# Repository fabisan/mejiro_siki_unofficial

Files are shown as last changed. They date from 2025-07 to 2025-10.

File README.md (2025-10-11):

# 初めに
勝手に作成したメジロ式配列のキーボードです
完成度は低いです

## 各フォルダの中身
CircuitBoard 
  回路図とガーバーデータ、KiCADデータ 
  JLCPCB
  PCB仕様は
    異なるデザイン：2
    納品形式：面付け済み
  HASL無鉛:$18.80 (5枚)

Firmware
  ファームウェアファイル

KeyCaps
  1uと2uのキーのSTLファイル、1個のみ・複数個バージョン
  JLC3DP
  複数個バージョン
    1u: $0.63
    2U: $1.47

plates
  アクリルプレートの加工図面
  遊舎工房に依頼したらすんなりデザインチェックOKでした
  作り直すので消しました

## 直したいところ
- 2Uキーの幅はもう少し長いと見た目がきれい
- ステムの穴はわずかに大きい。
    応急処置方法:穴をふさぐようにマステを貼って、スイッチに押し付けて取り付ける。(ChatGPT先生直伝)
- スタビライザーを付けたい。Y,#,*がわずかにぐらつく -> ステムを見直したら個人的に要らない気がした
- nキーは、t,kの逆側中央を少し盛り上げたい。完全に平面だと押しづらい
- Pro Micro版も作りたい -> 結局RP2040になりました

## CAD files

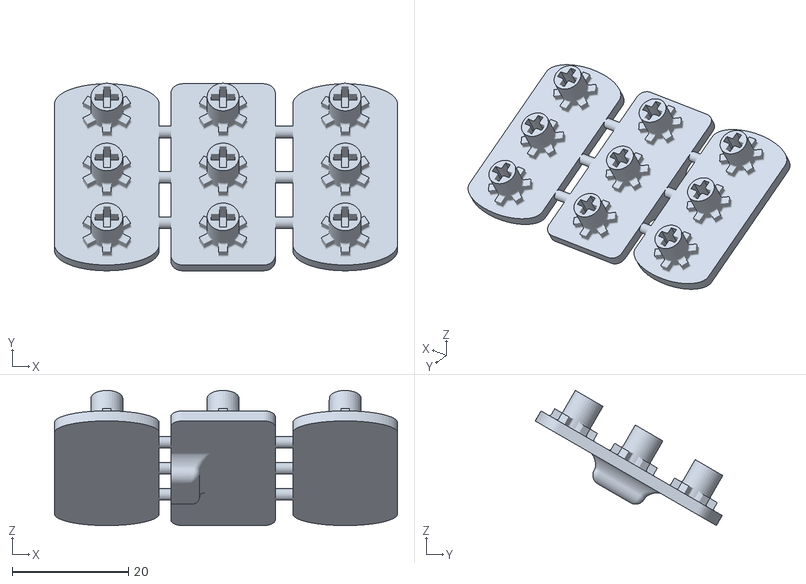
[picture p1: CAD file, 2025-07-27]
KeyCaps/mejiro_2ukeys v2.stl
59.0 x 32.3 x 23.3

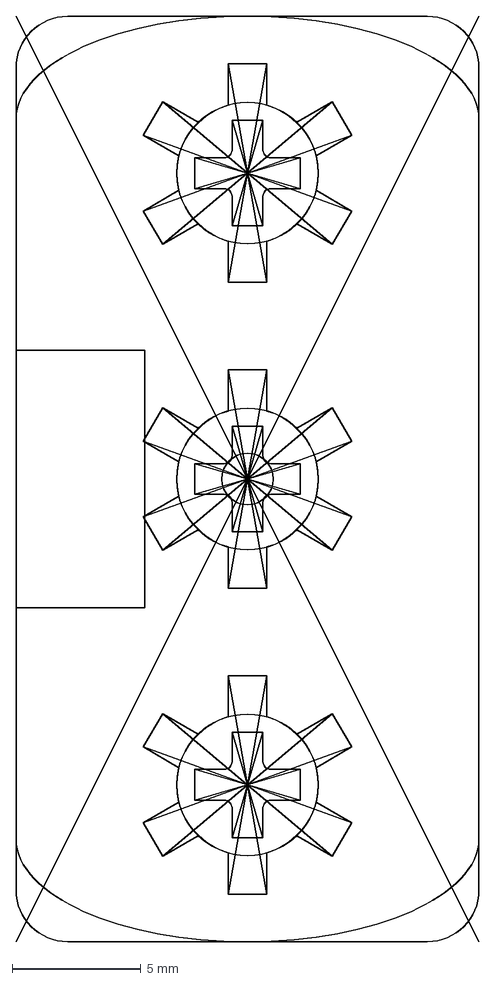
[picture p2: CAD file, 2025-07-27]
KeyCaps/mejiro_2uThumbs v3.dxf
18.0 x 36.0 mm

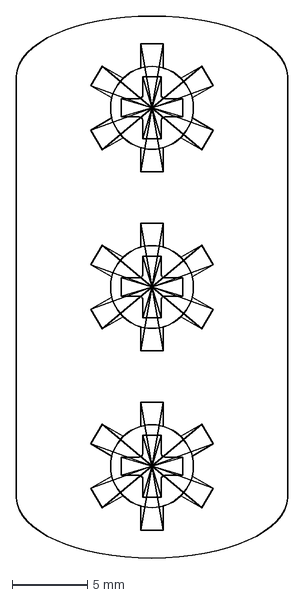
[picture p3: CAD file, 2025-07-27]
KeyCaps/mejiro_2uキー v5.dxf
18.0 x 36.0 mm

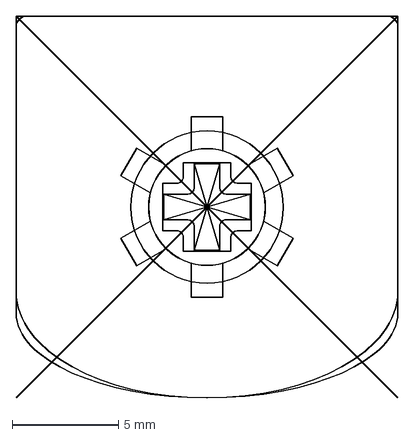
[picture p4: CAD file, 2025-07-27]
KeyCaps/mejiro_1u v8.dxf
18.0 x 18.0 mm

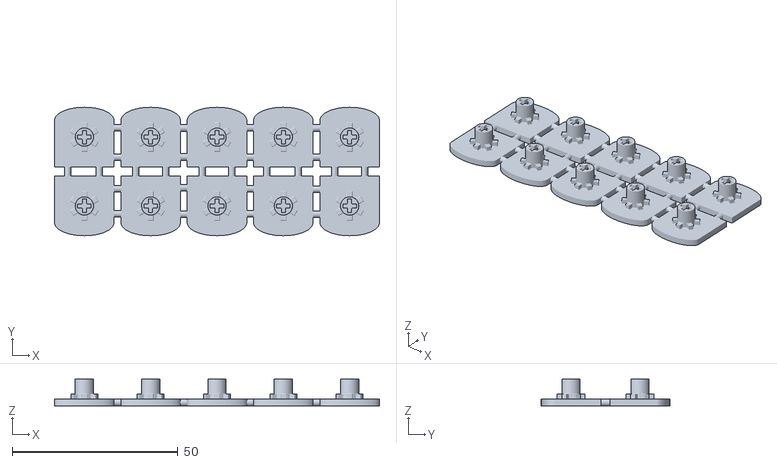
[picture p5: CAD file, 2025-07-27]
KeyCaps/mejiro_1u_x10 v3.stl
98.0 x 38.8 x 8.00

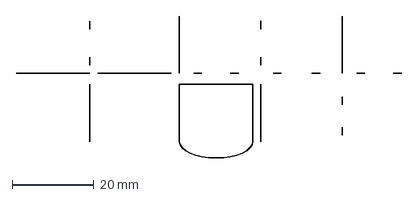
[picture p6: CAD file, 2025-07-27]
KeyCaps/mejiro_1u_x10 v4.dxf
94.5 x 34.8 mm

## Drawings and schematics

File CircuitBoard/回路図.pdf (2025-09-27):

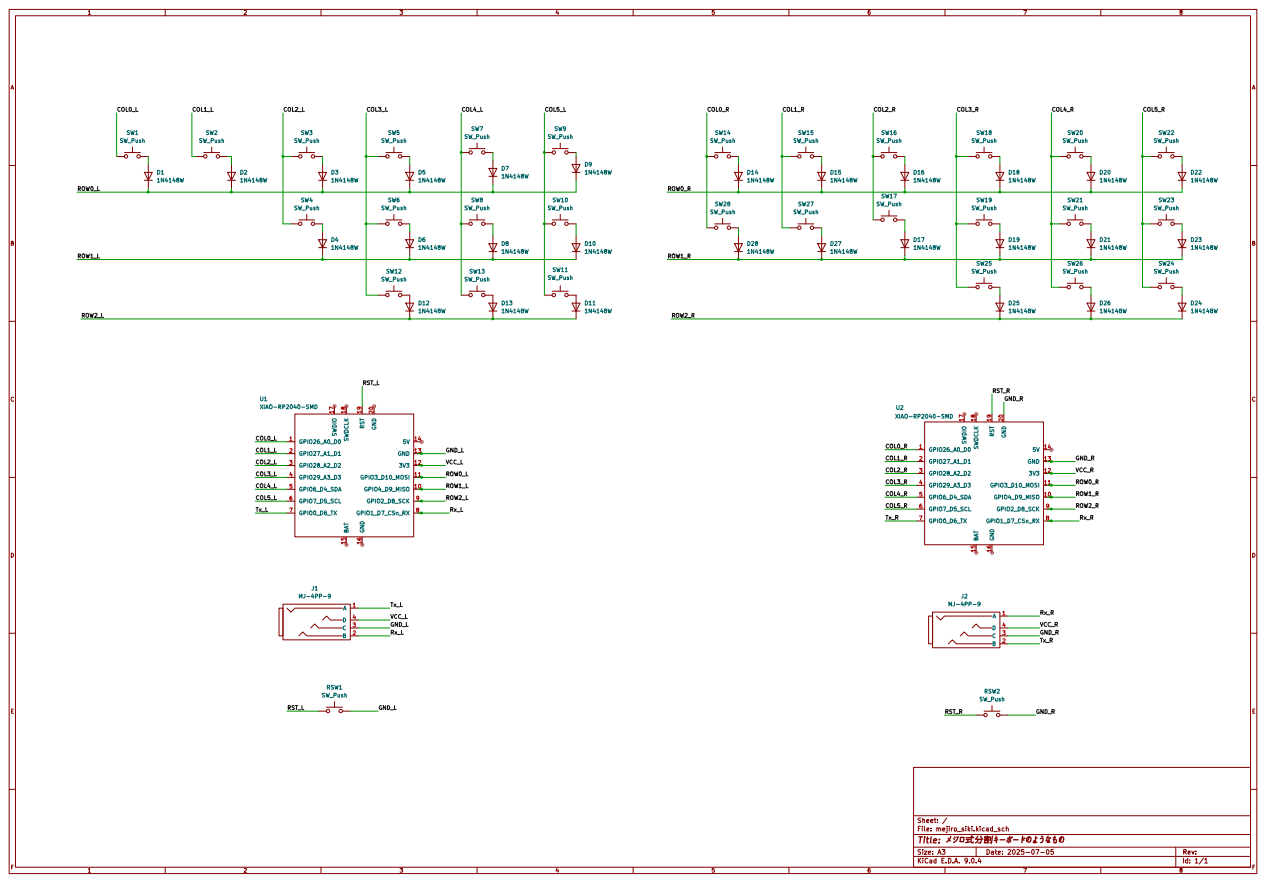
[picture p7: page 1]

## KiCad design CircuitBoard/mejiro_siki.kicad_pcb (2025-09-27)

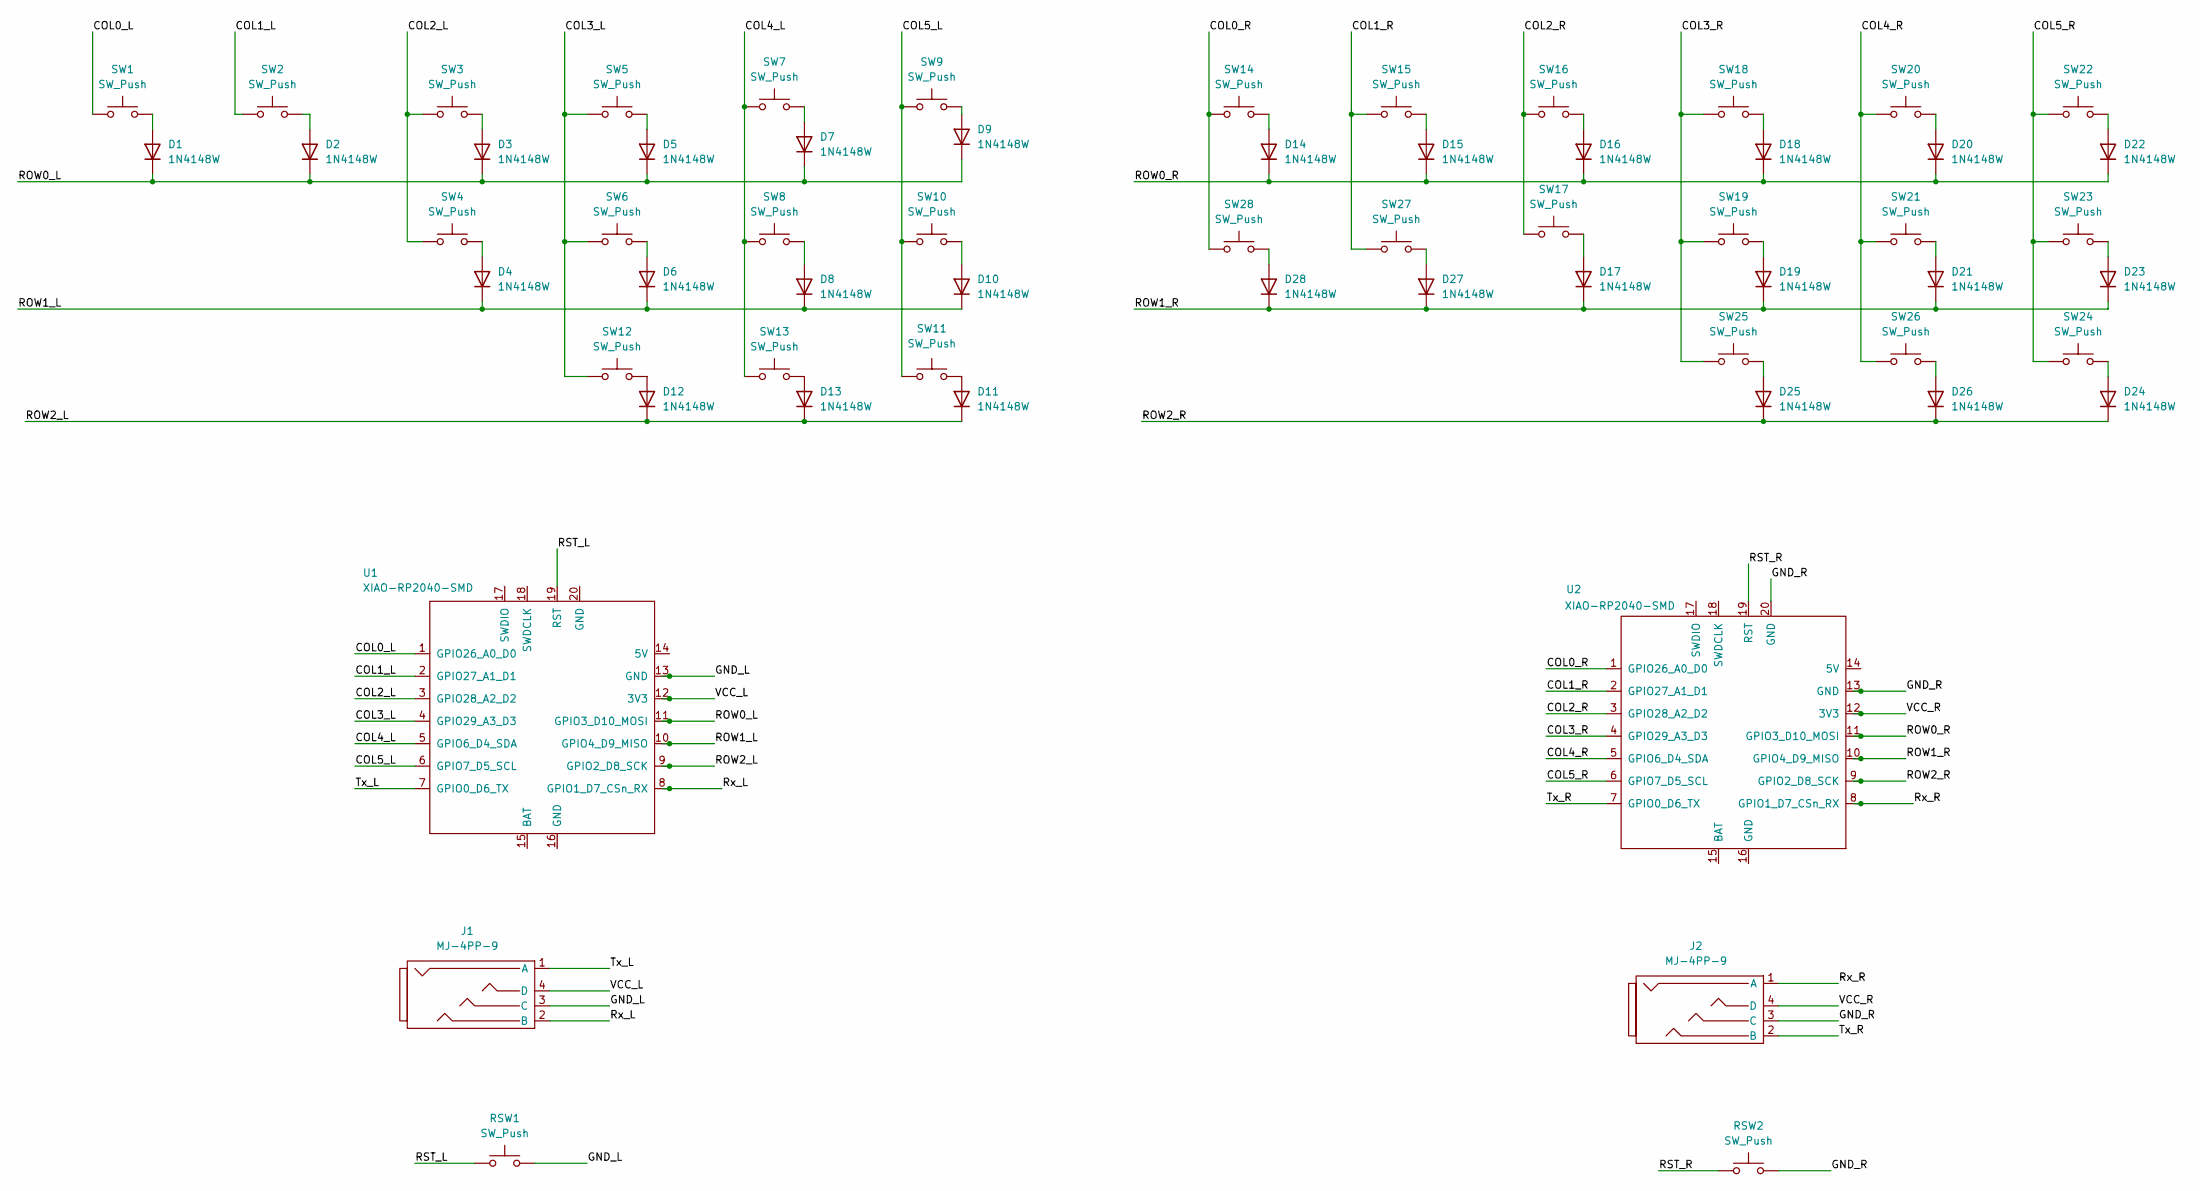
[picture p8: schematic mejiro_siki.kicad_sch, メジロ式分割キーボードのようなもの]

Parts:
D1, D2, D3, D4, D5, D6, D7, D8, D9, D10, D11, D12, D13, D14, D15, D16, D17, D18, D19, D20, D21, D22, D23, D24, D25, D26, D27, D28: 1N4148W; D_SOD-123
J1, J2: MJ-4PP-9
RSW1, RSW2: SW_Push; SKHLLCA010
SW1, SW2, SW3, SW4, SW5, SW6, SW7, SW8, SW9, SW10, SW11, SW12, SW13, SW14, SW15, SW16, SW17, SW18, SW19, SW20, SW21, SW22, SW23, SW24, SW25, SW26, SW27, SW28: SW_Push; CherryMX_Hotswap_via_1U
U1, U2: XIAO-RP2040-SMD

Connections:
/COL0_L: SW1.1, U1.1 (GPIO26_A0_D0)
/COL0_R: SW14.1, SW28.1, U2.1 (GPIO26_A0_D0)
/COL1_L: SW2.1, U1.2 (GPIO27_A1_D1)
/COL1_R: SW15.1, SW27.1, U2.2 (GPIO27_A1_D1)
/COL2_L: SW3.1, SW4.1, U1.3 (GPIO28_A2_D2)
/COL2_R: SW16.1, SW17.1, U2.3 (GPIO28_A2_D2)
/COL3_L: SW5.1, SW6.1, SW12.1, U1.4 (GPIO29_A3_D3)
/COL3_R: SW18.1, SW19.1, SW25.1, U2.4 (GPIO29_A3_D3)
/COL4_L: SW7.1, SW8.1, SW13.1, U1.5 (GPIO6_D4_SDA)
/COL4_R: SW20.1, SW21.1, SW26.1, U2.5 (GPIO6_D4_SDA)
/COL5_L: SW9.1, SW10.1, SW11.1, U1.6 (GPIO7_D5_SCL)
/COL5_R: SW22.1, SW23.1, SW24.1, U2.6 (GPIO7_D5_SCL)
/GND_L: J1.3 (C), RSW1.2, U1.13 (GND)
/GND_R: J2.3 (C), RSW2.2, U2.13 (GND), U2.20 (GND)
/ROW0_L: D1.1 (K), D2.1 (K), D3.1 (K), D5.1 (K), D7.1 (K), D9.1 (K), U1.11 (GPIO3_D10_MOSI)
/ROW0_R: D14.1 (K), D15.1 (K), D16.1 (K), D18.1 (K), D20.1 (K), D22.1 (K), U2.11 (GPIO3_D10_MOSI)
/ROW1_L: D4.1 (K), D6.1 (K), D8.1 (K), D10.1 (K), U1.10 (GPIO4_D9_MISO)
/ROW1_R: D17.1 (K), D19.1 (K), D21.1 (K), D23.1 (K), D27.1 (K), D28.1 (K), U2.10 (GPIO4_D9_MISO)
/ROW2_L: D11.1 (K), D12.1 (K), D13.1 (K), U1.9 (GPIO2_D8_SCK)
/ROW2_R: D24.1 (K), D25.1 (K), D26.1 (K), U2.9 (GPIO2_D8_SCK)
/RST_L: RSW1.1, U1.19 (RST)
/RST_R: RSW2.1, U2.19 (RST)
/Rx_L: J1.2 (B), U1.8 (GPIO1_D7_CSn_RX)
/Rx_R: J2.1 (A), U2.8 (GPIO1_D7_CSn_RX)
/Tx_L: J1.1 (A), U1.7 (GPIO0_D6_TX)
/Tx_R: J2.2 (B), U2.7 (GPIO0_D6_TX)
/VCC_L: J1.4 (D), U1.12 (3V3)
/VCC_R: J2.4 (D), U2.12 (3V3)
unnamed: D1.2 (A), SW1.2
unnamed: D2.2 (A), SW2.2
unnamed: D3.2 (A), SW3.2
unnamed: D4.2 (A), SW4.2
unnamed: D5.2 (A), SW5.2
unnamed: D6.2 (A), SW6.2
unnamed: D7.2 (A), SW7.2
unnamed: D8.2 (A), SW8.2
unnamed: D9.2 (A), SW9.2
unnamed: D10.2 (A), SW10.2
unnamed: D11.2 (A), SW11.2
unnamed: D12.2 (A), SW12.2
unnamed: D13.2 (A), SW13.2
unnamed: D14.2 (A), SW14.2
unnamed: D15.2 (A), SW15.2
unnamed: D16.2 (A), SW16.2
unnamed: D17.2 (A), SW17.2
unnamed: D18.2 (A), SW18.2
unnamed: D19.2 (A), SW19.2
unnamed: D20.2 (A), SW20.2
unnamed: D21.2 (A), SW21.2
unnamed: D22.2 (A), SW22.2
unnamed: D23.2 (A), SW23.2
unnamed: D24.2 (A), SW24.2
unnamed: D25.2 (A), SW25.2
unnamed: D26.2 (A), SW26.2
unnamed: D27.2 (A), SW27.2
unnamed: D28.2 (A), SW28.2

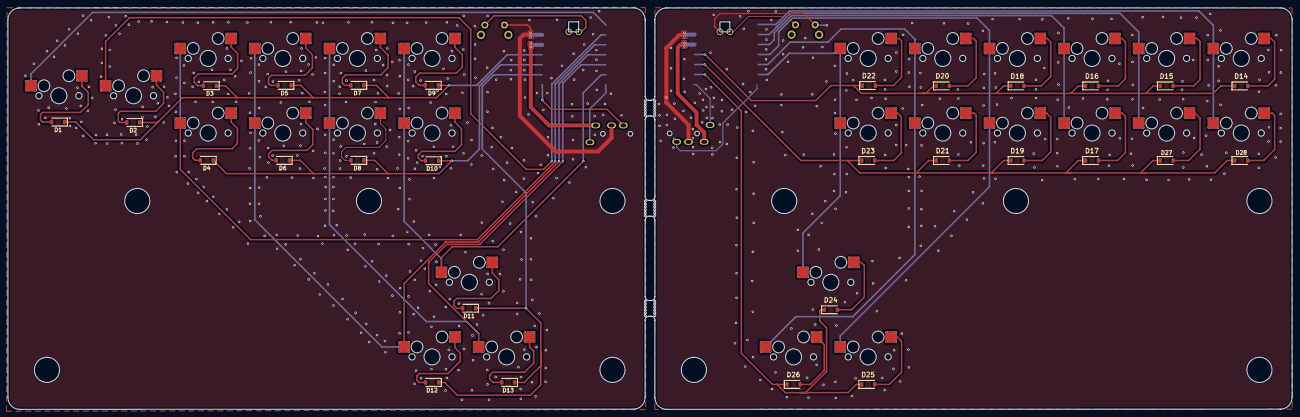
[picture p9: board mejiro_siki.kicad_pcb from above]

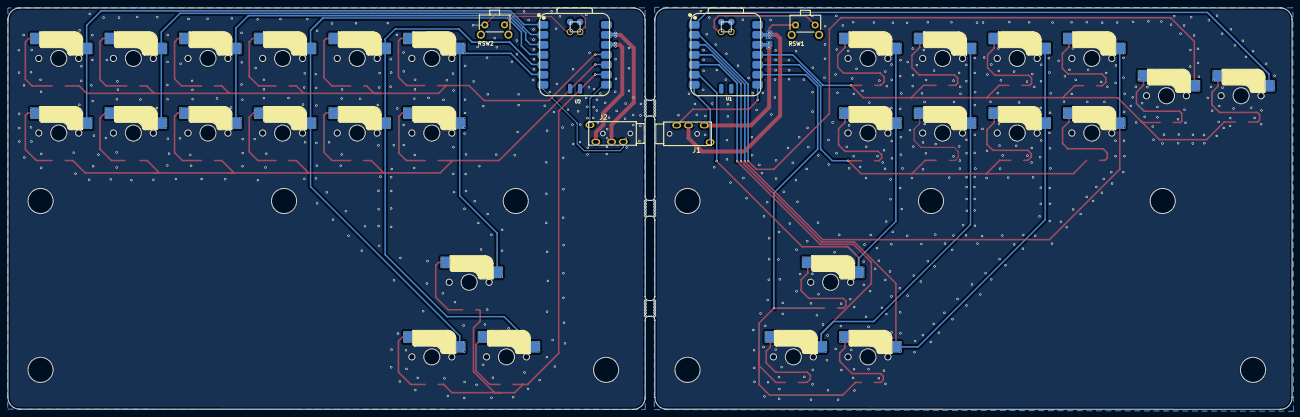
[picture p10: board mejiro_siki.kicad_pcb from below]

Board: 2 copper layers, 327.0 x 102.2 mm, 75 parts (6 on the bottom side), 56 nets.

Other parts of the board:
MB1, MB2, MB3: mousebites 2mm; mousebites_2.5mm
SP1, SP2, SP3, SP4, SP5, SP6, SP7, SP8, SP9, SP10: MountingHole_6.4mm_M6

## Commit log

2025-07-06 基板、1uキーキャップほぼ完成
    [mejiro_1u.stl, mejiro_1u_x9 v2.stl, mejiro_siki.kicad_pcb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]
2025-07-06 2uサイズキー完成
    [mejiro_2u.stl]
2025-07-06 2u 3個セット
    [mejiro_2u_x3.stl]
2025-07-06 ガーバーファイル追加
2025-07-06 遊舎工房依頼用ファイル作成
2025-07-19 buildできるかな？
2025-07-19 フォルダ構成変更
2025-07-19 拡張子修正
2025-07-19 ChatGPT先生の教えに従う
2025-07-19 zmkfirmware/unified-zmk-config-template を参考に
2025-07-19 zmk-configフォルダ内に戻しました
2025-07-19 build.yml を作成
2025-07-19 make config/Boards folder
2025-07-20 ファイル名を間違えていたのを修正
    [mejiro_1u_x10 v2.stl]
2025-07-21 写真載せときます
2025-07-27 Remake 1u key
    [mejiro_1u.stl, mejiro_1u_x10 v2.stl, mejiro_1u_x10 v3.stl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]
2025-07-27 Remake 2u key & Create 2u key for Thumbs
    [mejiro_2u.stl, mejiro_2u_x3.stl, ステノ_2uThumbs v1.stl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]
2025-07-27 2キーにフィレットをつけました
    [mejiro_1u v8.dxf, mejiro_1uキー v8.dxf, mejiro_2uThumbs v3.dxf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]
2025-08-23 練習用Ankiデッキ作成中
2025-08-28 Ankiデッキ更新
2025-08-28 Ankiデッキ@修正
2025-08-31 Ankiカード随時追加中
2025-09-27 基板更新(laptwing対応)
    [mejiro_siki.kicad_pcb, mejiro_siki.kicad_sch]
2025-09-27 回路図更新(laptwing対応)
2025-09-27 ガーバーデータ更新(laptwing対応)
2025-10-19 音節学習用Ankiカード作成
2025-10-22 助詞学習用Ankiカード作成
